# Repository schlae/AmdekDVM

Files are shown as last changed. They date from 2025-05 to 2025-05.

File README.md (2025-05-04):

# Amdek DVM Clone

The Amdek DVM allowed RGB digital monitors to be connected to Apple II
computers (which normally output composite video).

This project is a reverse-engineered version of this card.

It uses readily-available TTL logic chips, with no programmable devices at
all.

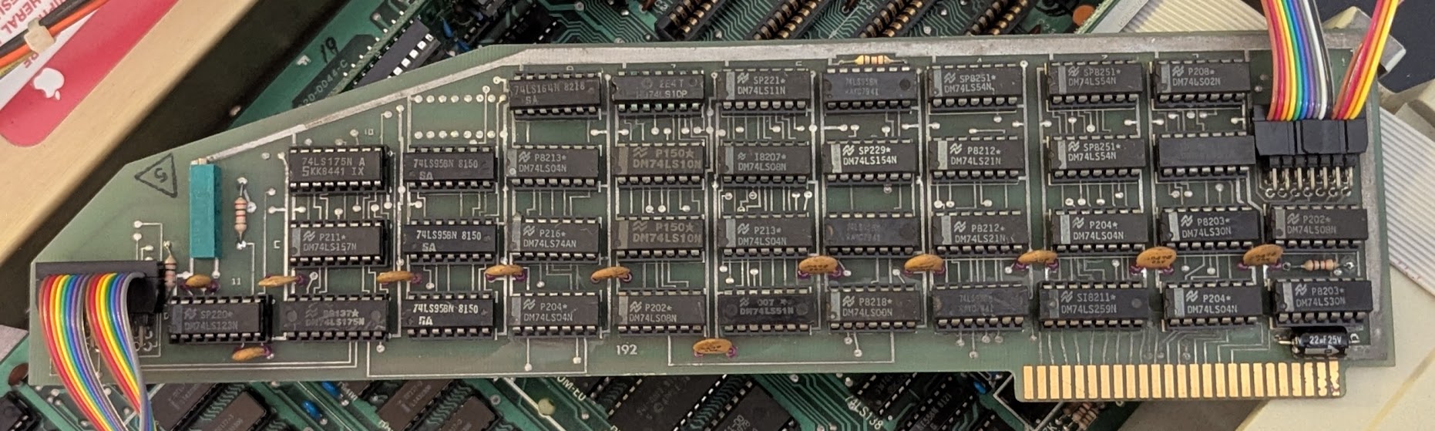
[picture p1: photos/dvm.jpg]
An original Amdek DVM card


*Note: The photo shows an original DVM card since I have not fabricated my design*

[Schematic](AmdekDVM.pdf)

[Bill of Materials](AmdekDVM.csv)

[Fab files](fab/AmdekDVM-Rev1.zip)

[Fab files for daughterboard](AmdekDaughterBoard/fab/AmdekDaughterBoard-Rev1.zip)

## Fabrication Notes

The main board is 280mm x 76mm (11" x 3"). It is a simple 2-layer board. It
has an edge connector on the bottom, and you may want to have it gold plated,
but this isn't strictly necessary. No edge bevel is required but it may make
it easier to insert into the connectors on the Apple II (or you could add
one with a file).

The daughterboard is 38mm x 87mm (1.5" x 3.435"). It is a simple 2-layer board
and could even be reduced down to a 1-layer design if you have access to such
a fab process.

## Assembly Notes

RV2 is actually a fixed resistor, 2K. Solder it from pin 1 to pin 3.

C3-C13 are just bypass capacitors and could easily be subbed out with 0.1uF.

C14-C23 are not stuffed on the original board, but it would be harmless
to place 0.1uF capacitors here.

The daughterboard (actually two separate boards, see the photos below) should
have machine-pin sockets installed. To allow them to be plugged into the Apple
II motherboard, solder additional socket pins (harvested from spare sockets)
to the ends of the pins protruding from the other side of the board. Alignment
is critical so that the pins will plug into the sockets on the Apple II.

The daughterboard can be assembled with regular 0.1" headers and 8-pin IDC
plugs, or you can use a combined part like the CA2308PA10Z. The cable is
split exactly in half, with the first 8 pins going to the 4-chip daughterboard
and the second 8 pins going to the 2-chip daughterboard (with wire 9 tied
to pin 1 of this daughterboard).

## Cables

To build this card, you will need a video output cable wired as follows. Plug
it into J2 (nearest the edge connector).

| Pin | Description |
|-----|---|
| 1 | Red output |
| 2 | Green output |
| 3 | Blue output |
| 4 | Horizontal sync (positive) |
| 5 | Horizontal sync (negative) |
| 6 | Vertical sync (positive) |
| 7 | Vertical sync (negative) |
| 8 | No connect |
| 9 | Ground |
| 10  | No connect |
| 11  | Apple II text - connect to Apple II header K14 pin 2 |
| 12  | Horizontal sync from 80-column card |
| 13  | Video signal from 80-column card |
| 14  | Vertical sync from 80-column card |

Pin 11 of this cable should be wired to the Apple II video header. On my
Apple II+, it looks like this.

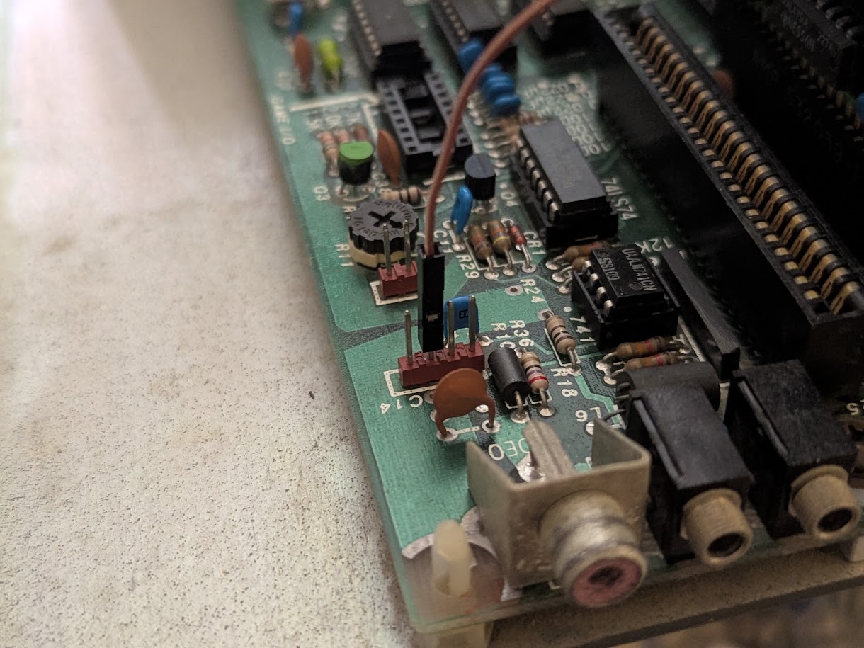
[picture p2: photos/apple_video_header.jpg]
Placement of the Apple II text connection


If you want to connect the DVM to a CGA-compatible monitor, wire it up as
follows:

| Amdek Pin | CGA Pin | Description |
|---|---|---|
| 1 |  3 | Red output  |
| 2 |  4 | Green output |
| 3 |  5 | Blue output |
| 4 |  8 | Horizontal sync (positive) |
| 6 |  9 | Vertical sync (positive) |
| 9 |  1 | Ground |

If you have an 80-column card, you can wire pins 12-14 to that card as
appropriate.

You will also need a cable connected to J1 (furthest from the edge connector)
wired to two daughterboards. The daughterboards act as interposers, tapping
various signals on the Apple II motherboard.

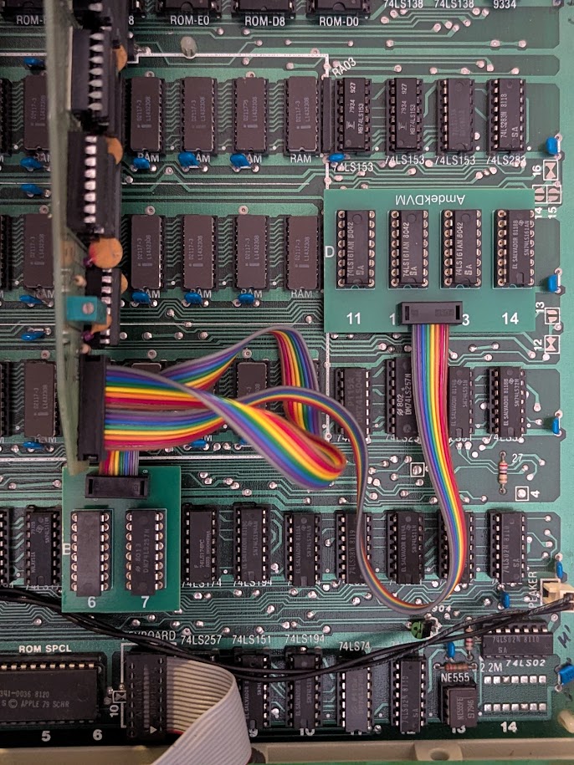
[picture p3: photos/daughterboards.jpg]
Placement of the daughterboards


* One daughterboard sits on motherboard positions D11, D12, D13, and D14,
hosting the four 74LS161 chips that the Apple II uses to generate the video
timing signals. It intercepts three horizontal counter bits and five vertical
counter bits.

* The other daughterboard sits on motherboard positions B6 and B7, hosting
two 74LS257 chips. This intercepts the eight digital video bits before
they go through encoding to composite video.

## Adjustments

When you install the card, ensure you get video out of your Apple II, then
adjust RV1 until you get stable pixels.

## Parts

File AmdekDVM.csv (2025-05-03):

Qty | Reference | Value | DNP | Exclude from BOM | Exclude from Board
1 | C1 | 100
1 | C2 | 33
10 | C3,C4,C5,C6,C7,C8,C9,C10,C11,C12 | 0.047
1 | C13 | 22uF 25V
10 | C14,C15,C16,C17,C18,C19,C20,C21,C22,C23 | DNI
1 | J1 | TO_DAUGHTERBOARD
1 | J2 | VIDEO
1 | J3 | APPLE II
1 | R1 | 10K
2 | R2,R3 | 1K
1 | RV1 | 5K
1 | RV2 | 2K
1 | U1 | 74LS123
2 | U2,U4 | 74LS175
1 | U3 | 74LS157
1 | U5 | SPARE
6 | U6,U7,U8,U21,U23,U28 | 74LS95
2 | U9,U22 | 74LS164
5 | U10,U12,U19,U31,U36 | 74LS04
1 | U11 | 74LS74
3 | U13,U14,U15 | 74LS10
3 | U16,U18,U37 | 74LS08
1 | U17 | 74LS11
2 | U20,U34 | 74LS51
1 | U24 | 74LS00
3 | U25,U29,U30 | 74LS54N
2 | U26,U27 | 74LS21
1 | U32 | 74LS259
1 | U33 | 74LS02
2 | U35,U38 | 74LS30

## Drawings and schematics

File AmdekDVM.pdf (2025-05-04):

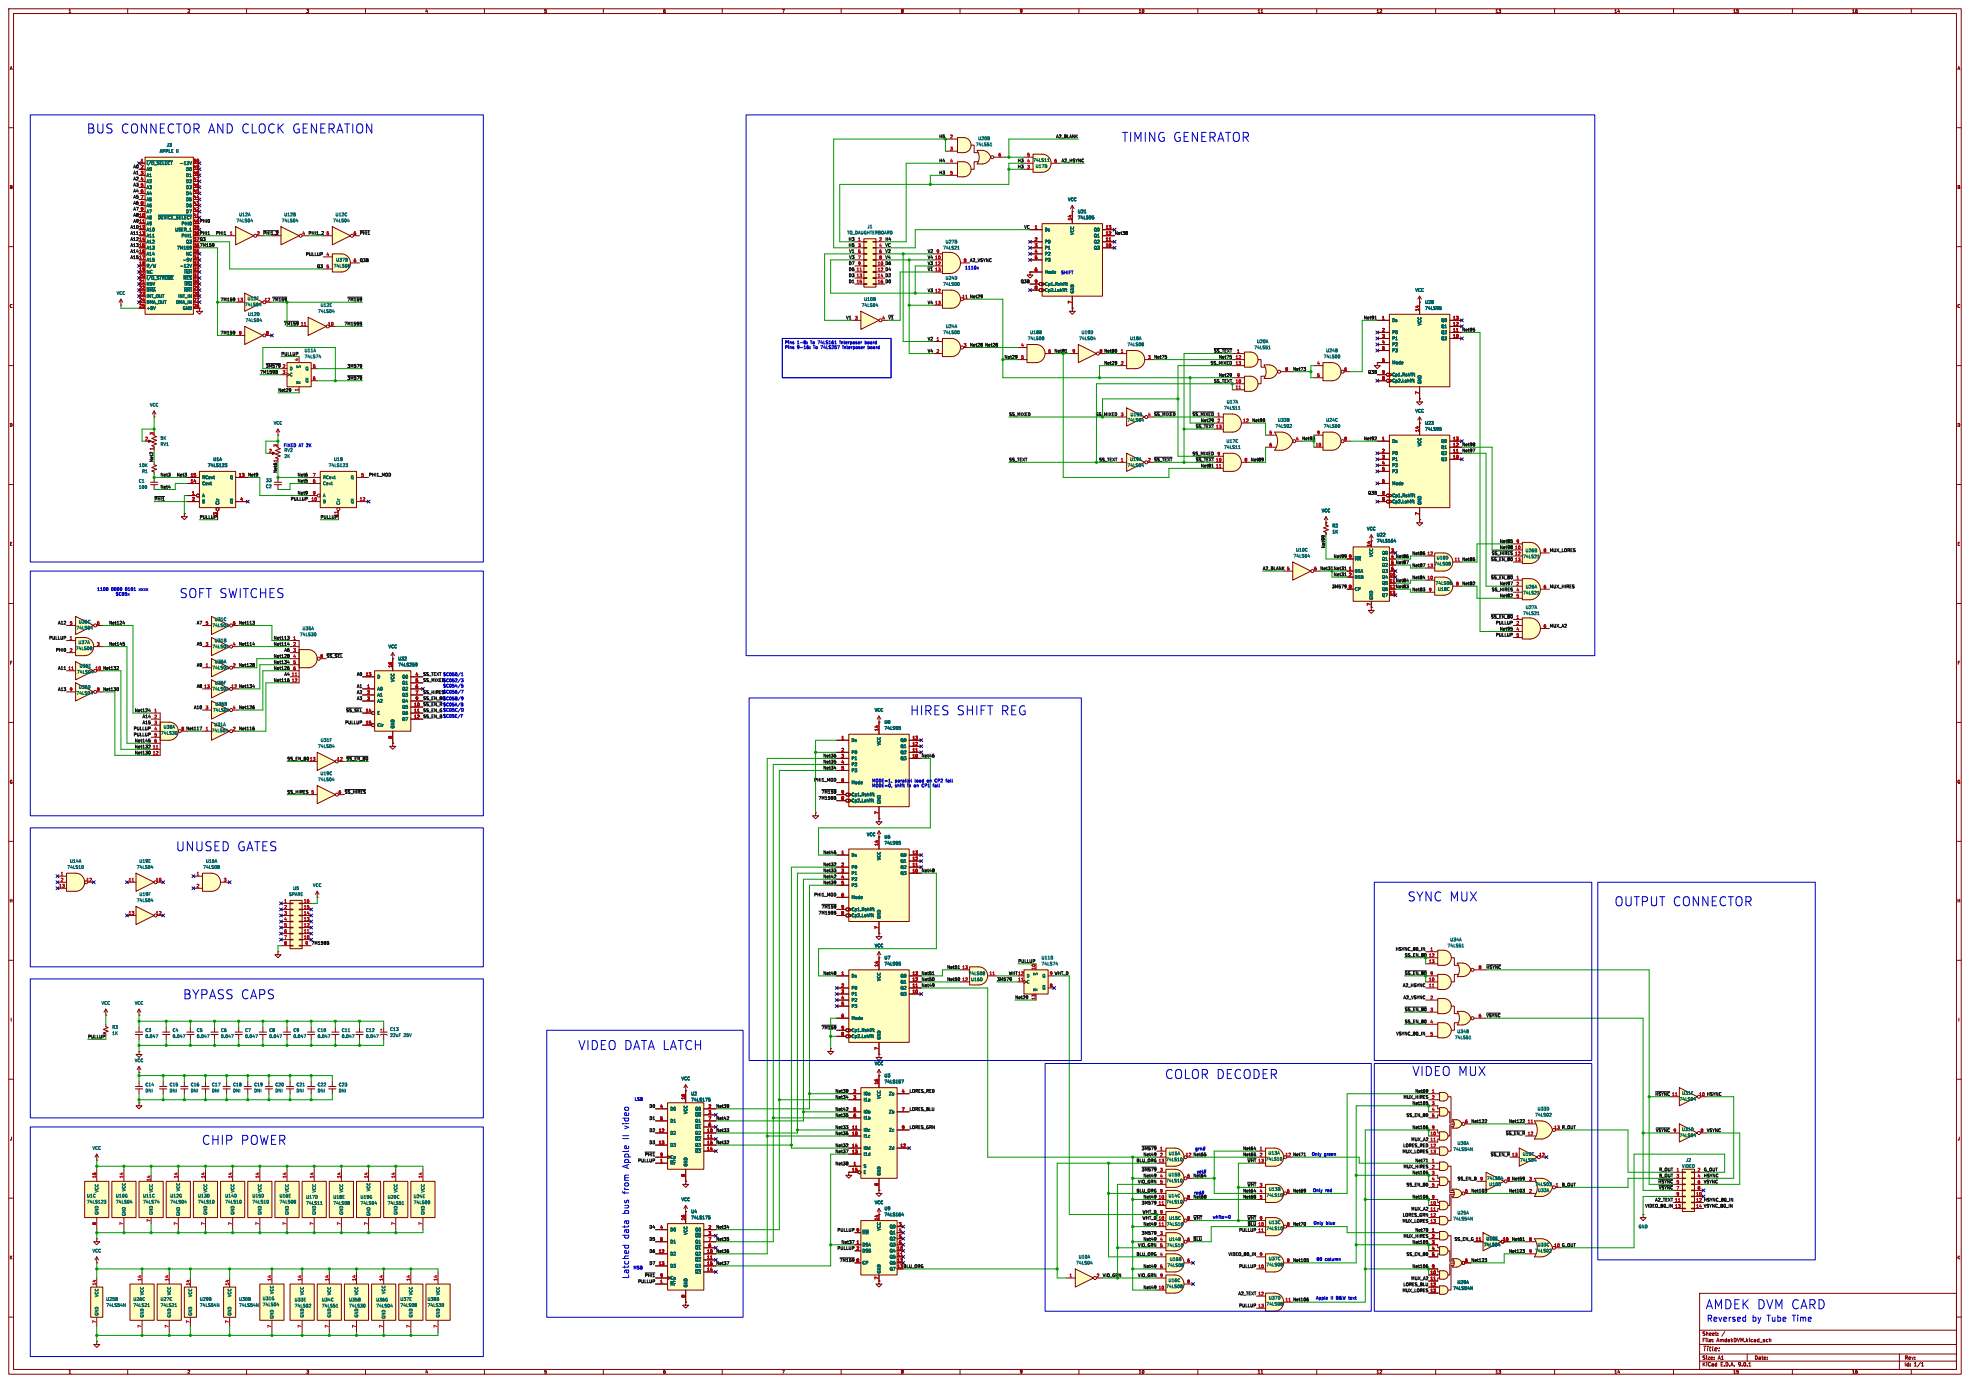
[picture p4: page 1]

BUS CONNECTOR AND CLOCK GENERATION
J3 APPLE II ~{I/O_SELECT} 1 A0 2 A1 3 A2 4 A3 5 A4 6 A5 7 A6 8 A7 9 A8 10 A9 11 A10 12 A11 13 A12 14 A13 15 A14 16 A15 17 R/W 18 NC 19 ~{I/O_STROBE} 20 RDY 21 ~{DMA} 22
-12V 50 D0 49 D1 48 D2 47 D3 46 D4 45 D5 44 D6 43 D7 42 ~{DEVICE_SELECT} 41 PHI0 40 USER_1 39 PHI1 38 Q3 37

-12V 33 ~{INH}32 ~{RES} 31 ~{IRQ} 30 ~{NMI}29

Only blue CHIP POWER

AMDEK DVM CARD
Reversed by Tube Time

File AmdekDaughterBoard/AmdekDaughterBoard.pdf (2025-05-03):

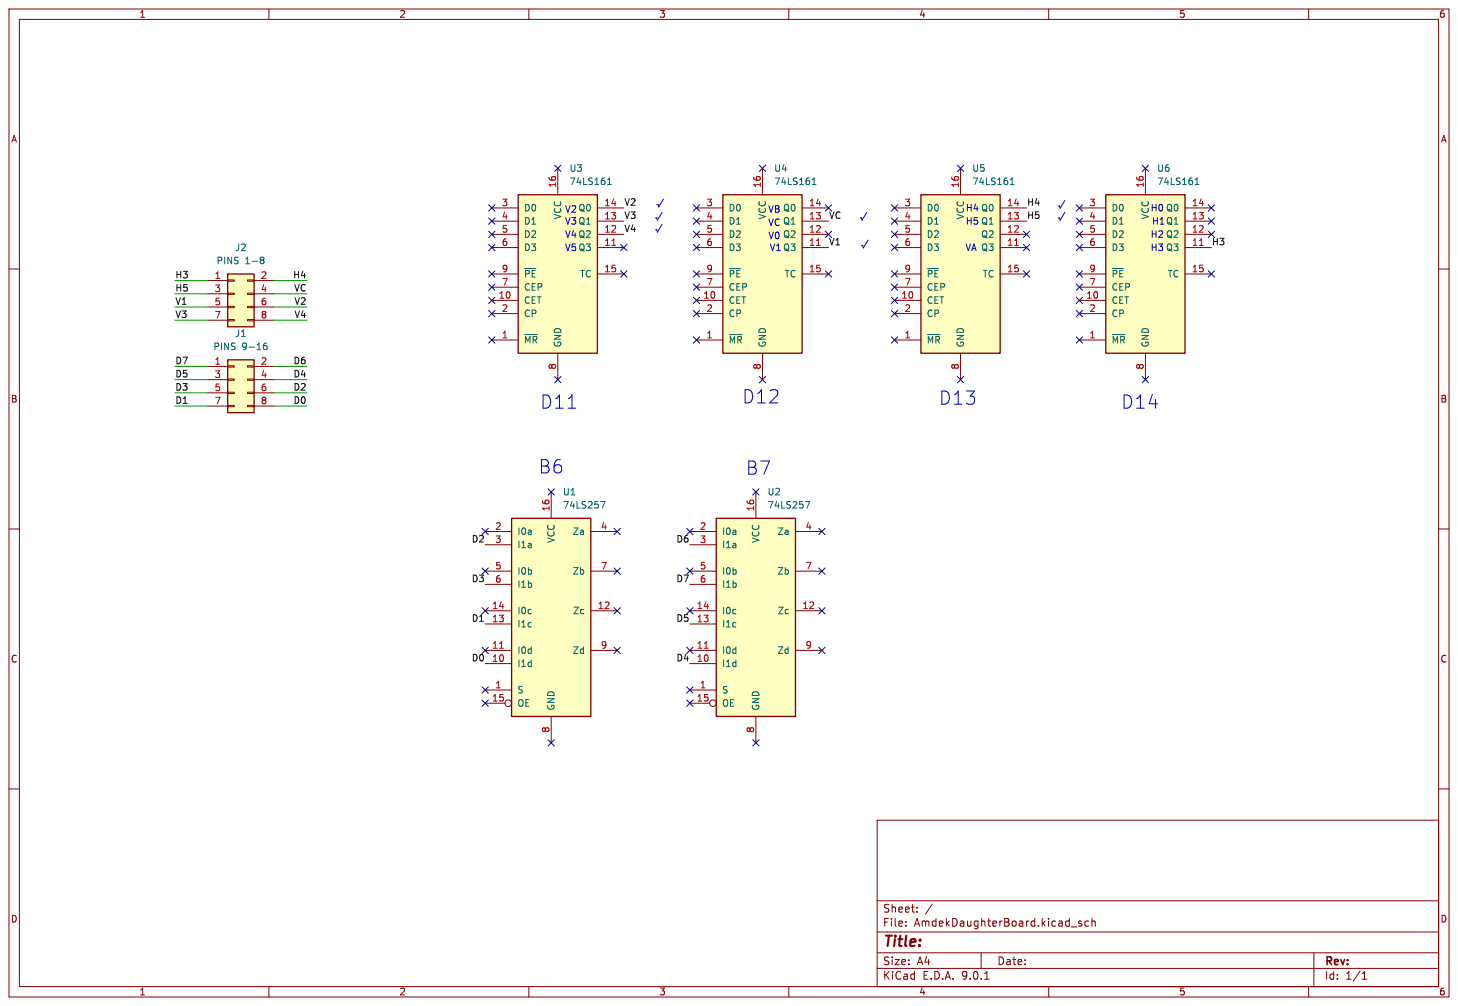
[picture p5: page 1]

Id: 1/1 Title: File: AmdekDaughterBoard.kicad_sch Sheet: /

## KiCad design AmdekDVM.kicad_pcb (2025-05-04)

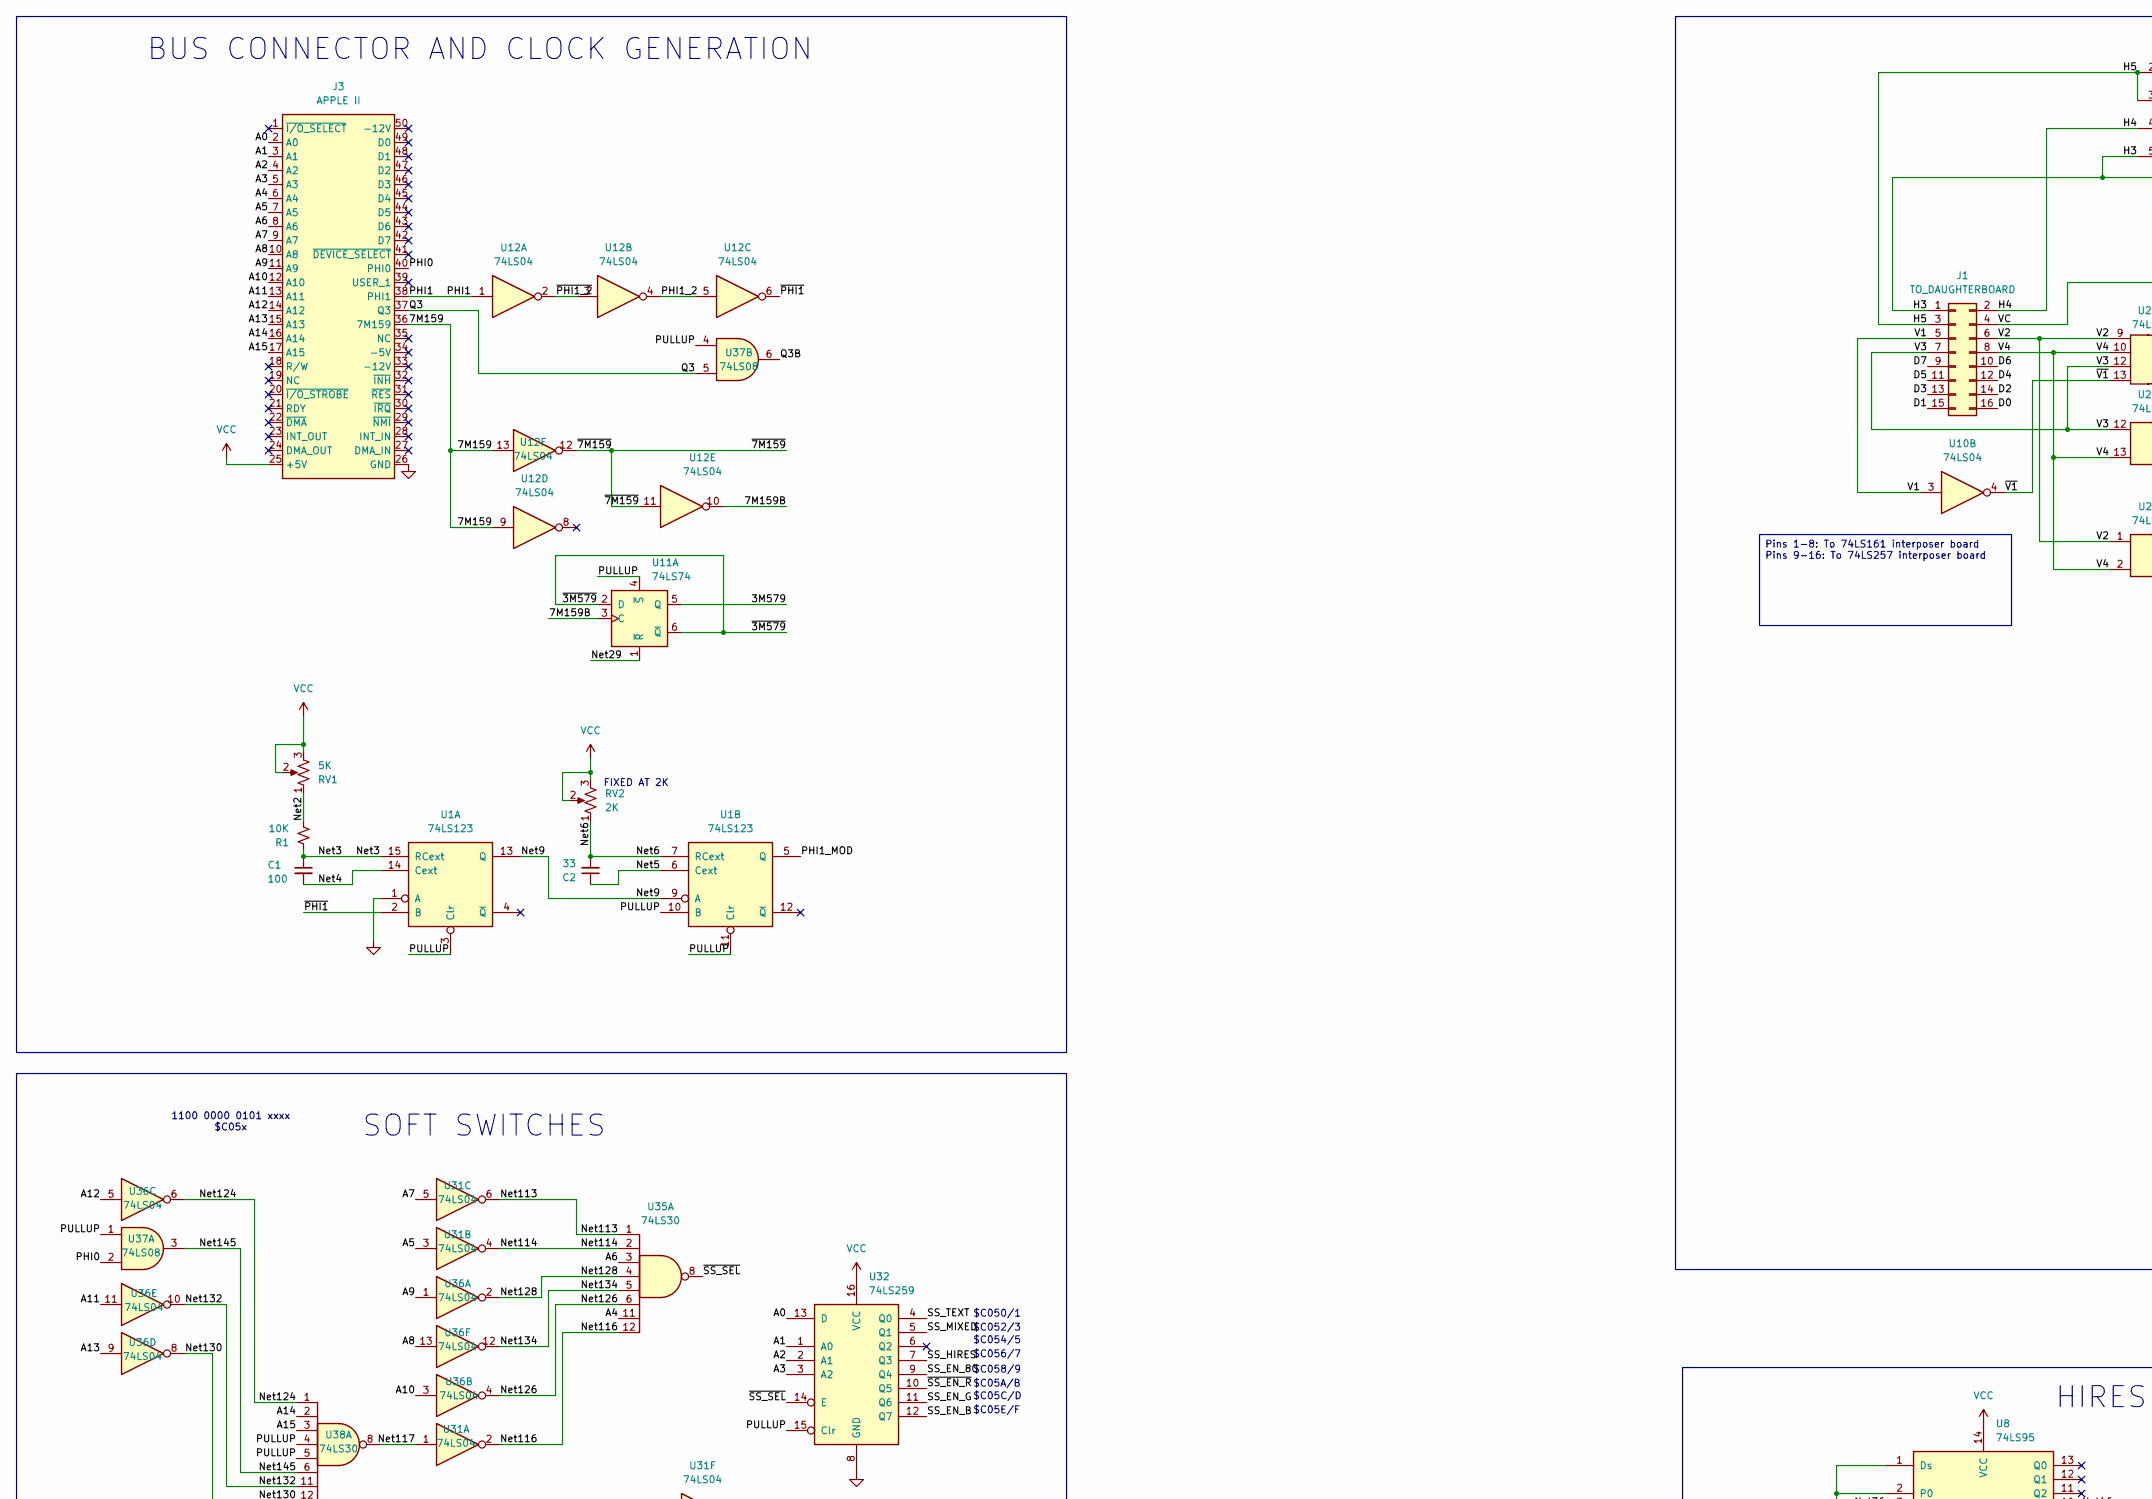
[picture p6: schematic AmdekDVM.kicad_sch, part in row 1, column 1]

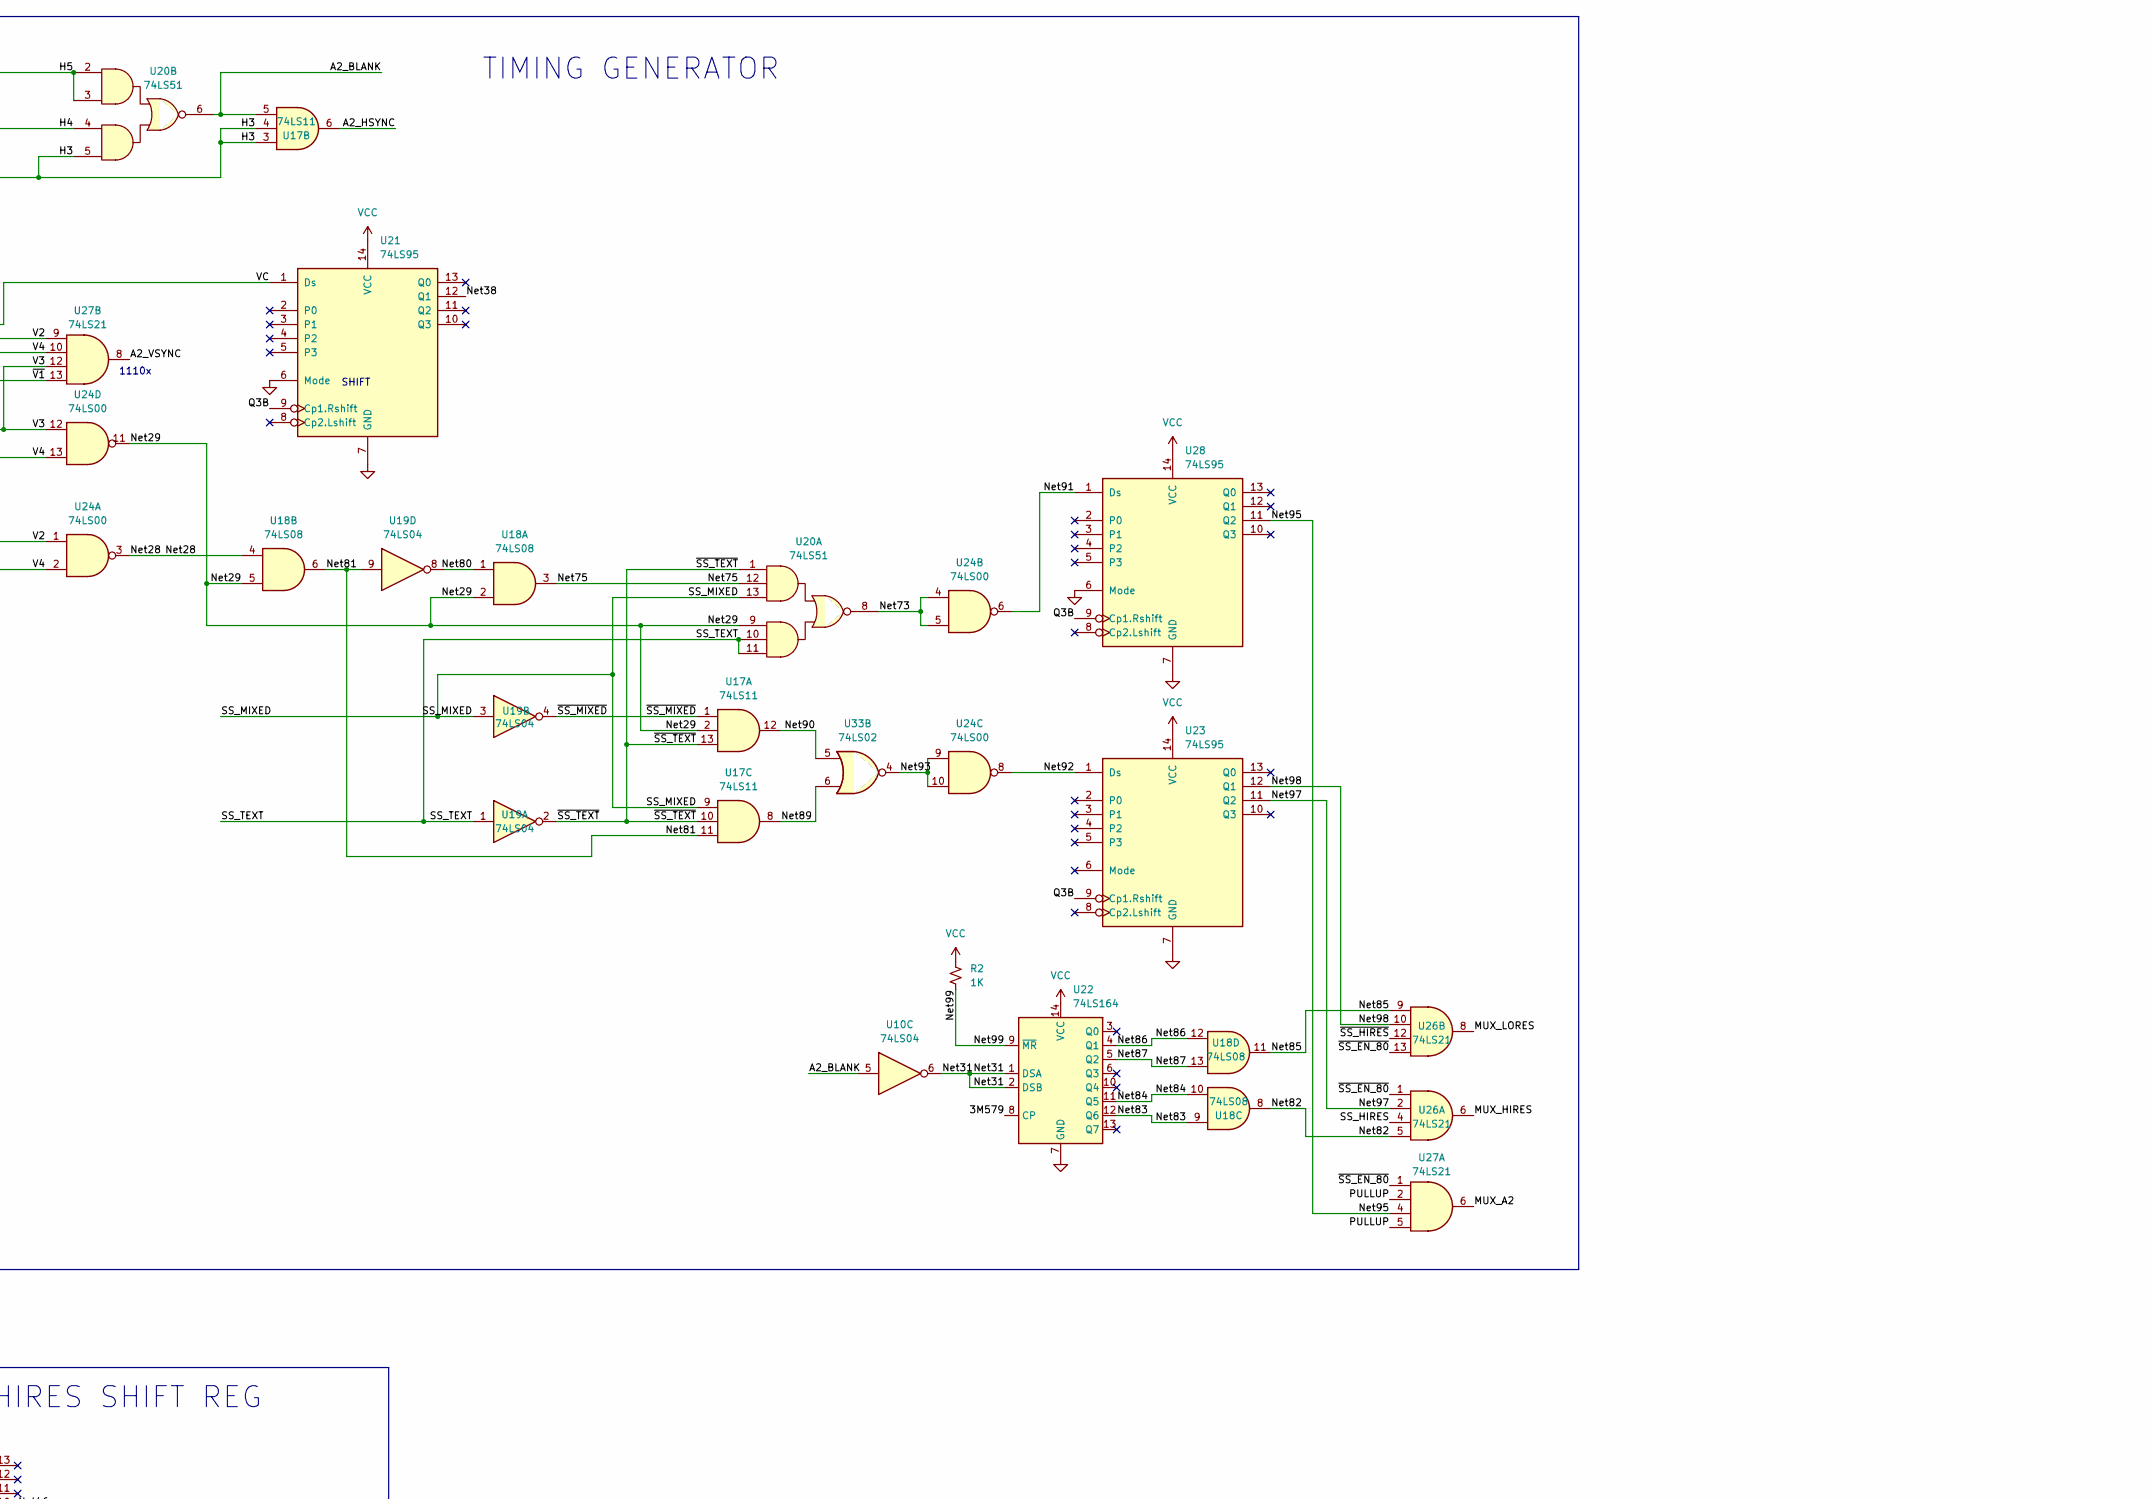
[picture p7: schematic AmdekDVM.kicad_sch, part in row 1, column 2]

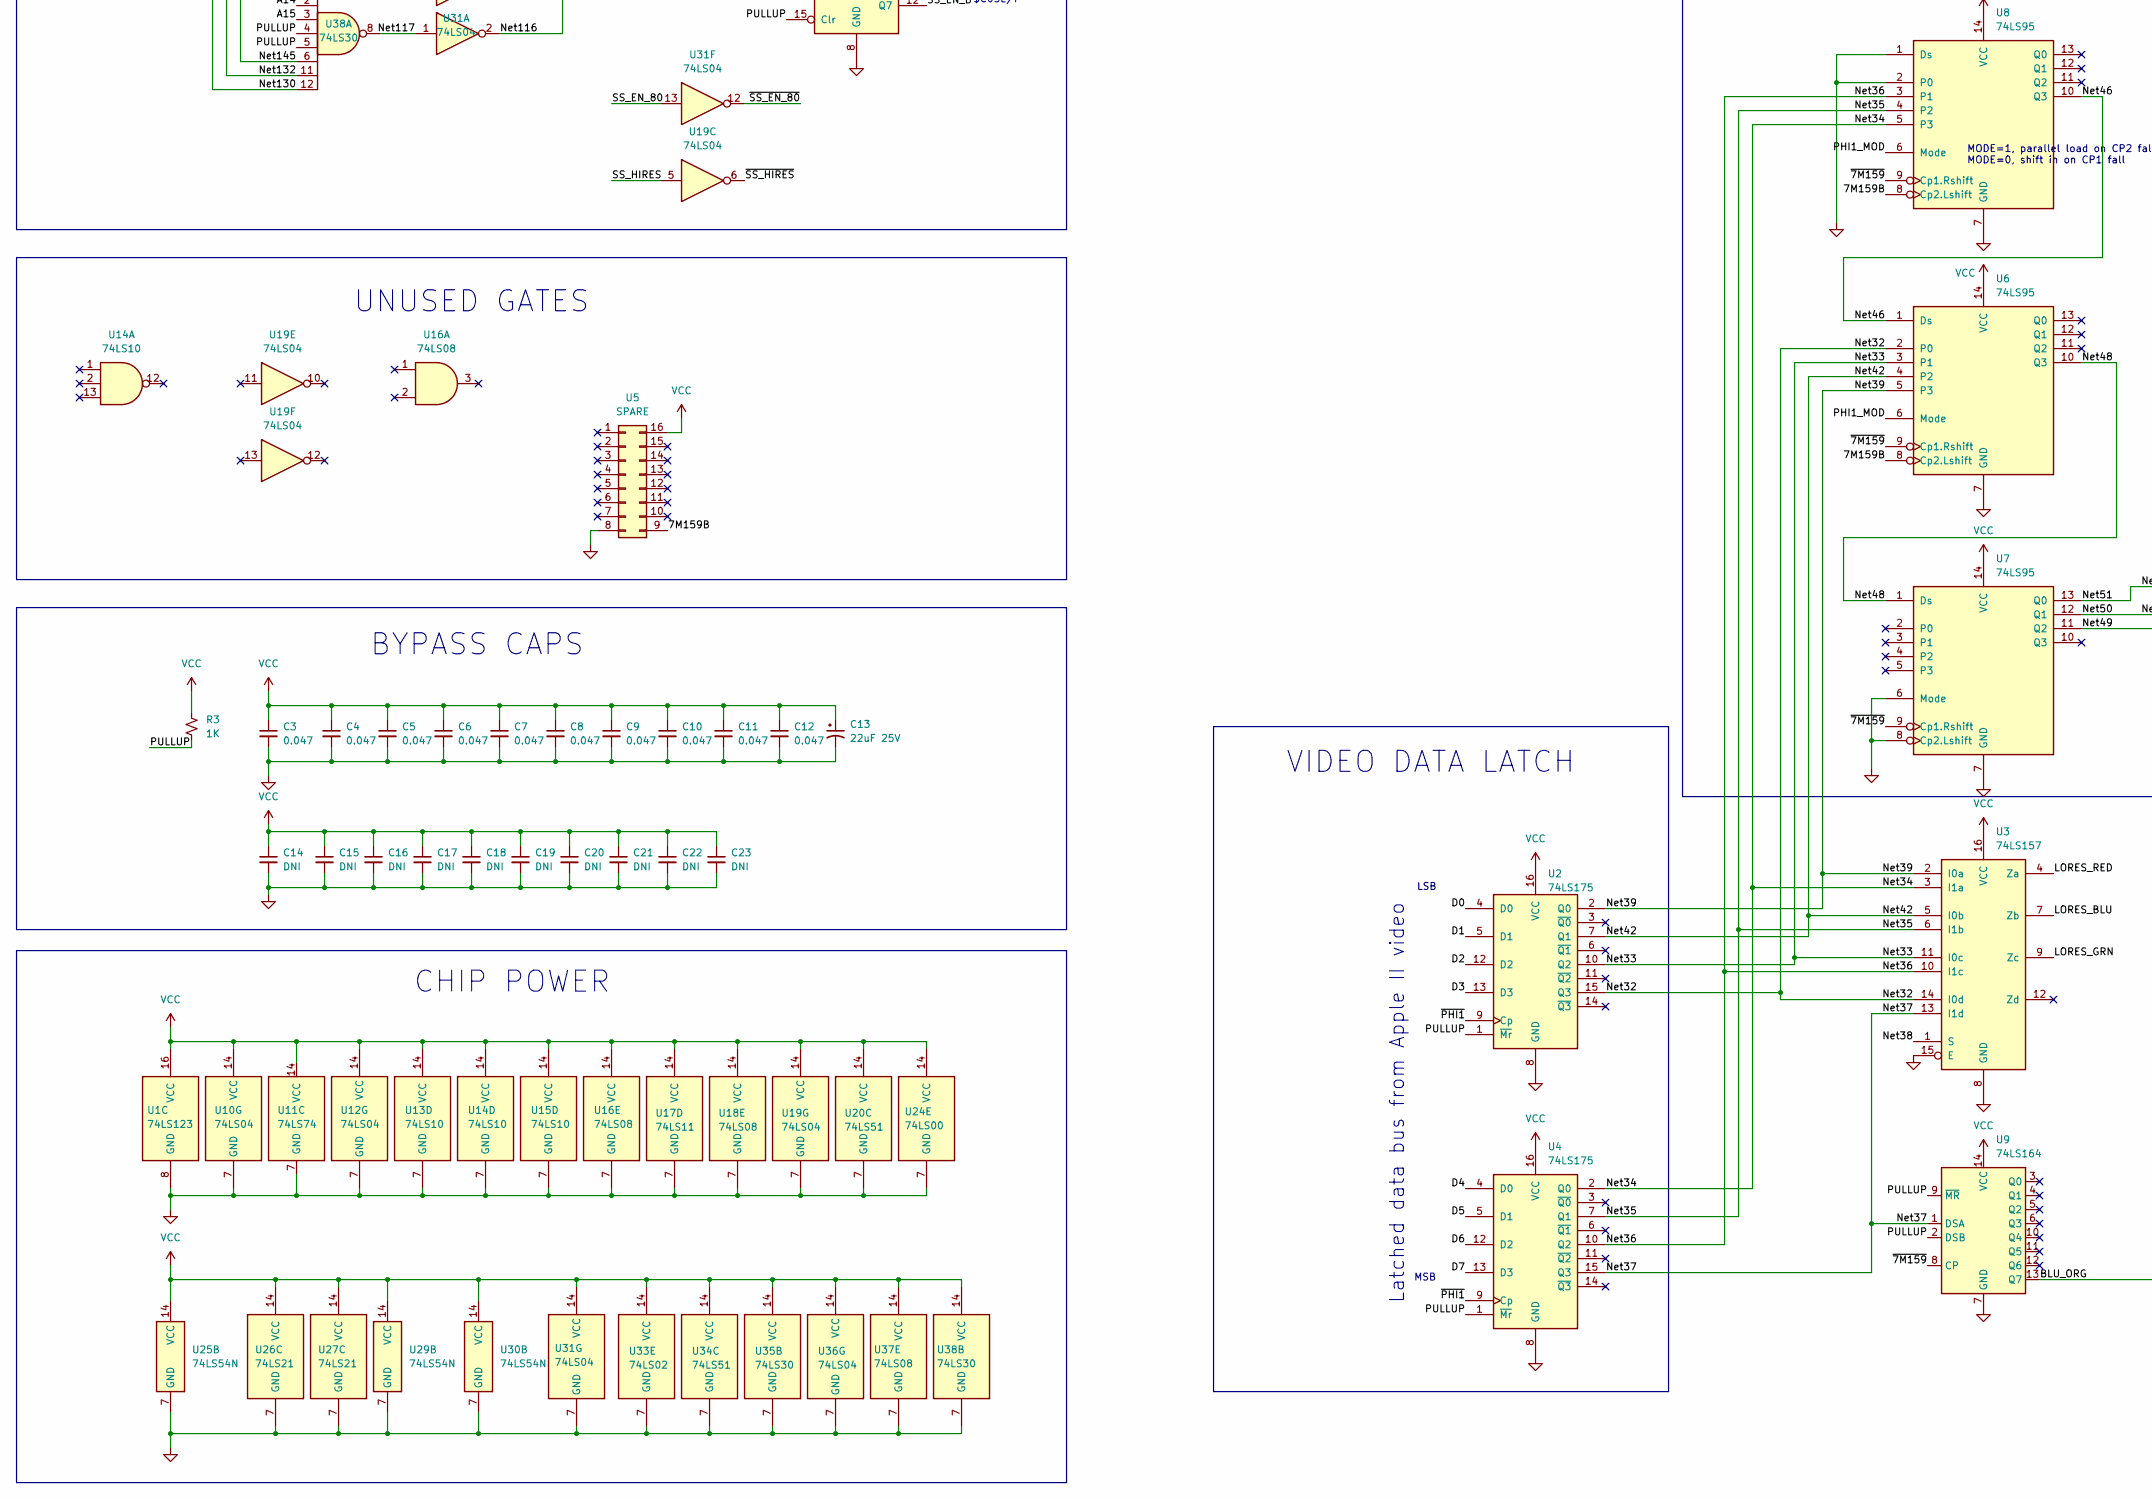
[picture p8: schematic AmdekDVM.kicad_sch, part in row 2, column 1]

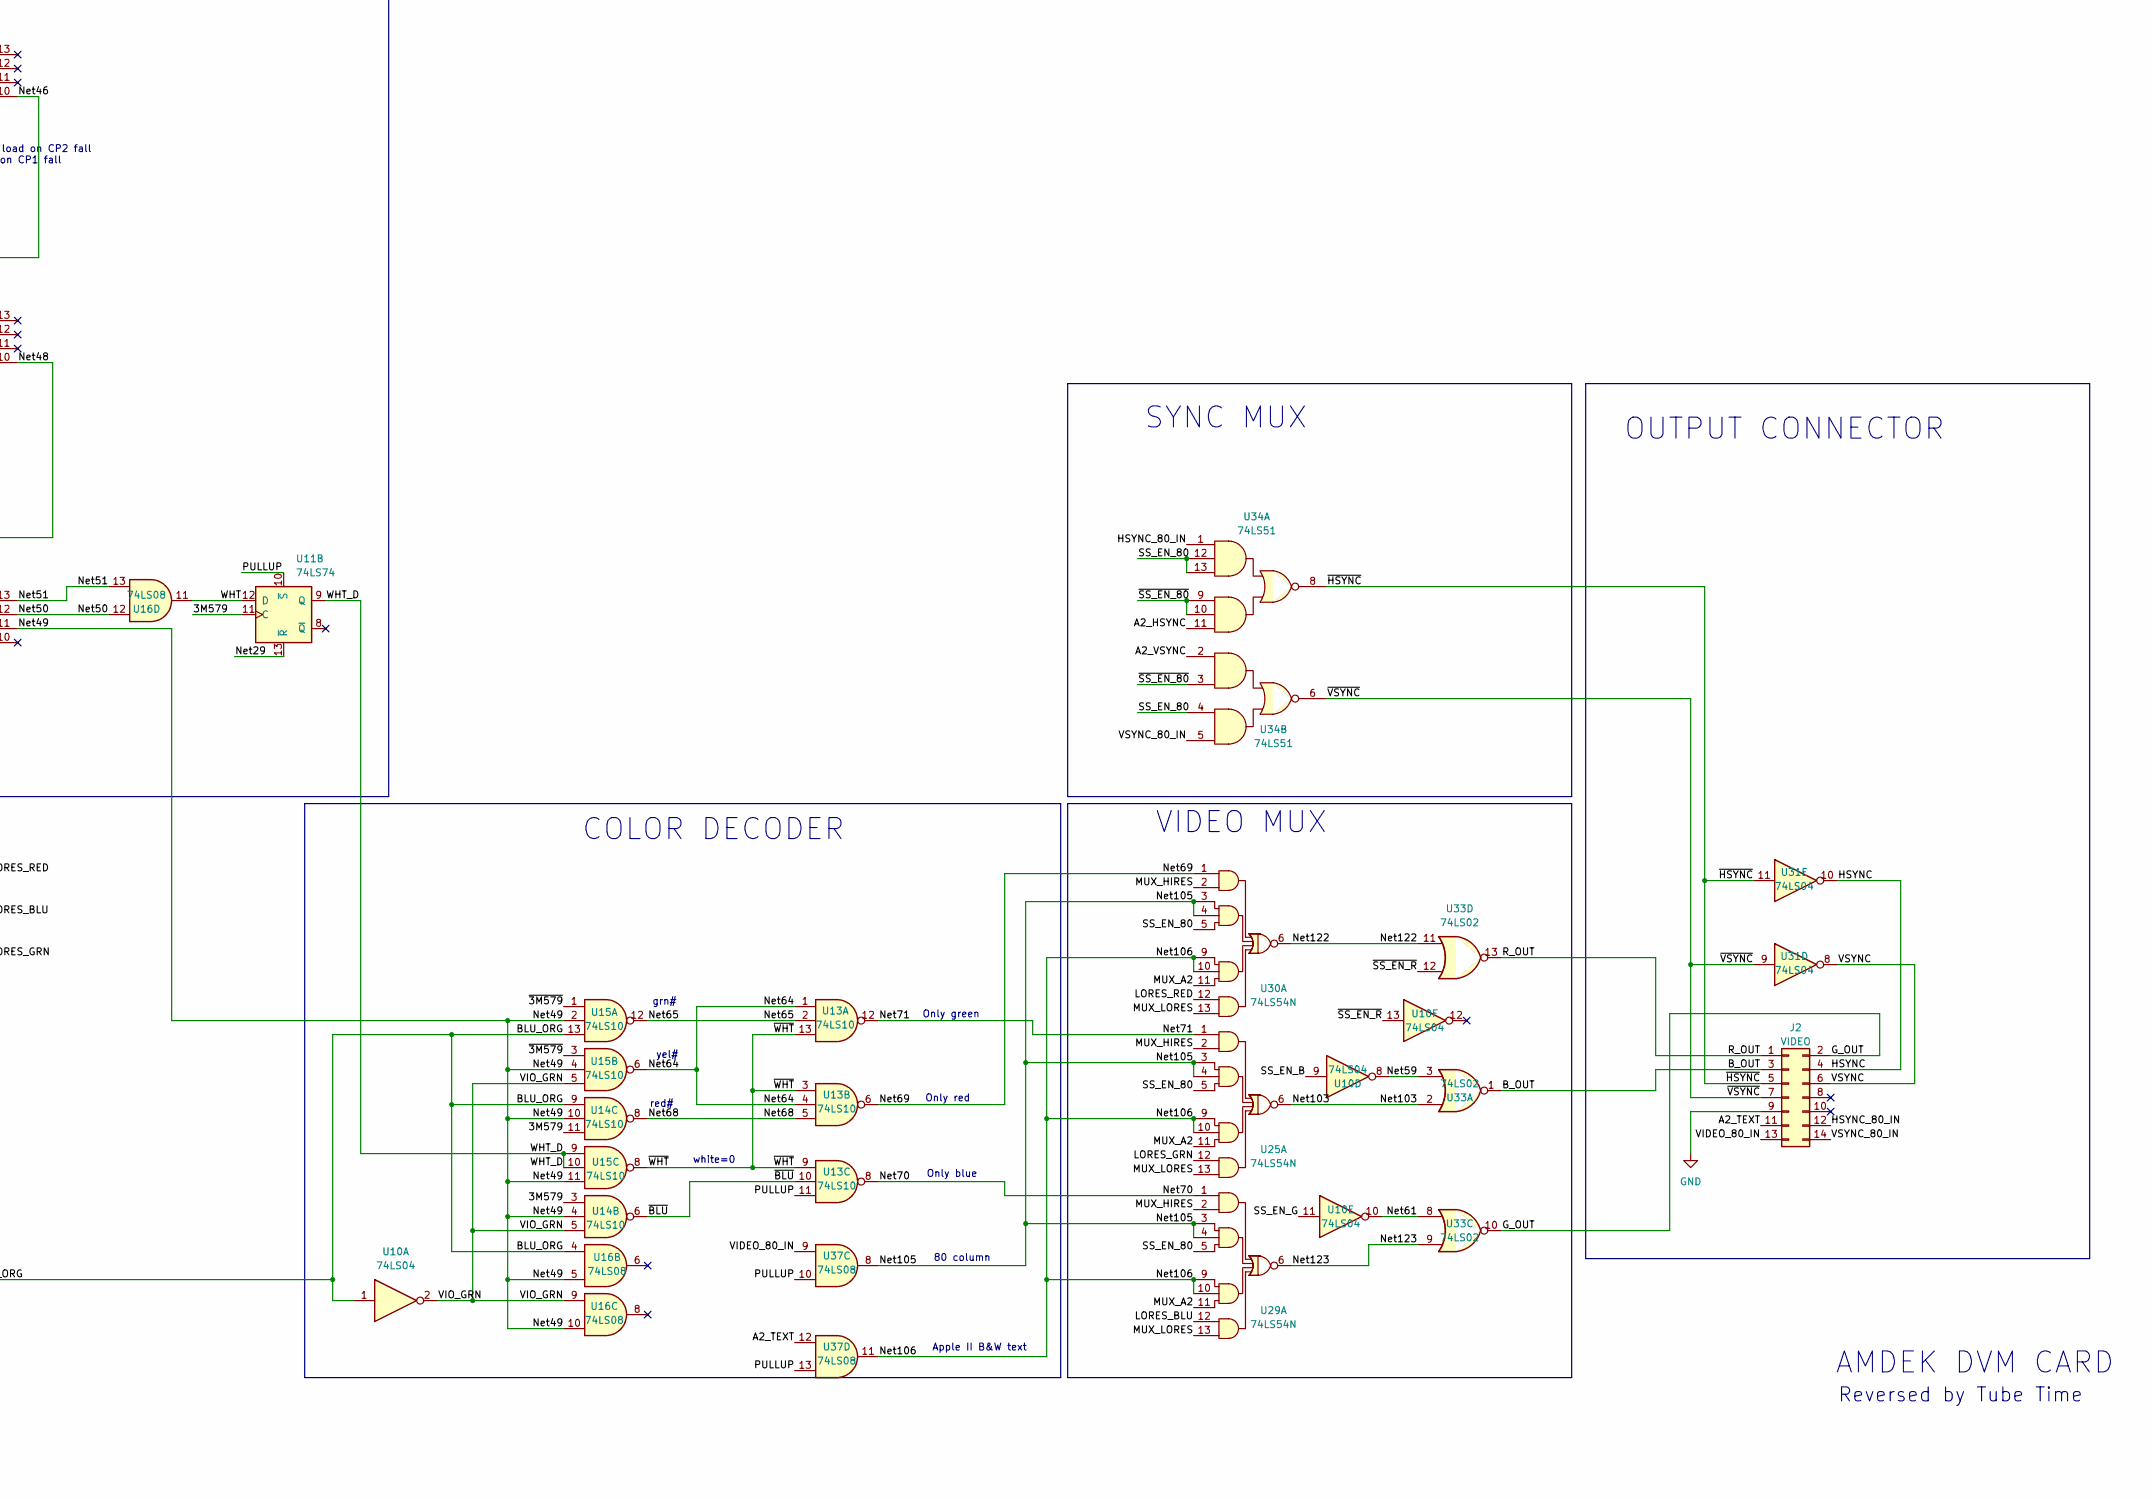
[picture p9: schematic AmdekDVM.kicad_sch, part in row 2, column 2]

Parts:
C1: 100; C_Disc_D4.3mm_W1.9mm_P5.00mm
C2: 33; C_Disc_D4.3mm_W1.9mm_P5.00mm
C3, C4, C5, C6, C7, C8, C9, C10, C11, C12: 0.047; C_Disc_D4.3mm_W1.9mm_P5.00mm
C13: 22uF 25V; CP_Axial_L10.0mm_D4.5mm_P15.00mm_Horizontal
C14, C15, C16, C17, C18, C19, C20, C21, C22, C23: DNI; C_Disc_D4.3mm_W1.9mm_P5.00mm
J1: TO_DAUGHTERBOARD; PinHeader_2x08_P2.54mm_Horizontal
J2: VIDEO; PinHeader_2x07_P2.54mm_Horizontal
J3: APPLE II; APPLE_II
R1: 10K; R_Axial_DIN0309_L9.0mm_D3.2mm_P12.70mm_Horizontal
R2, R3: 1K; R_Axial_DIN0309_L9.0mm_D3.2mm_P12.70mm_Horizontal
RV1: 5K; Potentiometer_Bourns_3006P_Horizontal
RV2: 2K; Potentiometer_Bourns_3006P_Horizontal
U1: 74LS123; DIP-16_W7.62mm
U2, U4: 74LS175; DIP-16_W7.62mm
U3: 74LS157; DIP-16_W7.62mm
U5: SPARE; DIP-16_W7.62mm
U6, U7, U8, U21, U23, U28: 74LS95; DIP-14_W7.62mm
U9, U22: 74LS164; DIP-14_W7.62mm
U10, U12, U19, U31, U36: 74LS04; DIP-14_W7.62mm
U11: 74LS74; DIP-14_W7.62mm
U13, U14, U15: 74LS10; DIP-14_W7.62mm
U16, U18, U37: 74LS08; DIP-14_W7.62mm
U17: 74LS11; DIP-14_W7.62mm
U20, U34: 74LS51; DIP-14_W7.62mm
U24: 74LS00; DIP-14_W7.62mm
U25, U29, U30: 74LS54N; DIP-14_W7.62mm
U26, U27: 74LS21; DIP-14_W7.62mm
U32: 74LS259; DIP-16_W7.62mm
U33: 74LS02; DIP-14_W7.62mm
U35, U38: 74LS30; DIP-14_W7.62mm

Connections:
/3M579: U11.5 (Q), U11.11 (C), U14.3, U14.11, U22.8 (CP)
/7M159: J3.36 (7M159), U12.9, U12.13
/7M159B: U5.9, U6.8 (Cp2.Lshift), U8.8 (Cp2.Lshift), U11.3 (C), U12.10
/A0: J3.2 (A0), U32.13 (D)
/A1: J3.3 (A1), U32.1 (A0)
/A2: J3.4 (A2), U32.2 (A1)
/A2_BLANK: U10.5, U17.5, U20.6
/A2_HSYNC: U17.6, U34.11
/A2_TEXT: J2.11, U37.12
/A2_VSYNC: U27.8, U34.2
/A3: J3.5 (A3), U32.3 (A2)
/A4: J3.6 (A4), U35.11
/A5: J3.7 (A5), U31.3
/A6: J3.8 (A6), U35.3
/A7: J3.9 (A7), U31.5
/A8: J3.10 (A8), U36.13
/A9: J3.11 (A9), U36.1
/A10: J3.12 (A10), U36.3
/A11: J3.13 (A11), U36.11
/A12: J3.14 (A12), U36.5
/A13: J3.15 (A13), U36.9
/A14: J3.16 (A14), U38.2
/A15: J3.17 (A15), U38.3
/BLU_ORG: U9.13 (Q7), U10.1, U14.9, U15.13, U16.4
/B_OUT: J2.3, U33.1
/D0: J1.16, U2.4 (D0)
/D1: J1.15, U2.5 (D1)
/D2: J1.14, U2.12 (D2)
/D3: J1.13, U2.13 (D3)
/D4: J1.12, U4.4 (D0)
/D5: J1.11, U4.5 (D1)
/D6: J1.10, U4.12 (D2)
/D7: J1.9, U4.13 (D3)
/G_OUT: J2.2, U33.10
/H3: J1.1, U17.3, U17.4, U20.5
/H4: J1.2, U20.4
/H5: J1.3, U20.2, U20.3
/HSYNC: J2.4, U31.10
/HSYNC_80_IN: J2.12, U34.1
/LORES_BLU: U3.7 (Zb), U29.12
/LORES_GRN: U3.9 (Zc), U25.12
/LORES_RED: U3.4 (Za), U30.12
/MUX_A2: U25.11, U27.6, U29.11, U30.11
/MUX_HIRES: U25.2, U26.6, U29.2, U30.2
/MUX_LORES: U25.13, U26.8, U29.13, U30.13
/Net2: R1.2, RV1.1
/Net3: C1.1, R1.1, U1.15 (RCext)
/Net4: C1.2, U1.14 (Cext)
/Net5: C2.1, U1.6 (Cext)
/Net6: C2.2, RV2.1, U1.7 (RCext)
/Net9: U1.9 (A), U1.13 (Q)
/Net28: U18.4, U24.3
/Net29: U11.1 (~R), U11.13 (~R), U17.2, U18.2, U18.5, U20.9, U24.11
/Net31: U10.6, U22.1 (DSA), U22.2 (DSB)
/Net32: U2.15 (Q3), U3.14 (I0d), U6.2 (P0)
/Net33: U2.10 (Q2), U3.11 (I0c), U6.3 (P1)
/Net34: U3.3 (I1a), U4.2 (Q0), U8.5 (P3)
/Net35: U3.6 (I1b), U4.7 (Q1), U8.4 (P2)
/Net36: U3.10 (I1c), U4.10 (Q2), U8.3 (P1)
/Net37: U3.13 (I1d), U4.15 (Q3), U9.1 (DSA)
/Net38: U3.1 (S), U21.12 (Q1)
/Net39: U2.2 (Q0), U3.2 (I0a), U6.5 (P3)
/Net42: U2.7 (Q1), U3.5 (I0b), U6.4 (P2)
/Net46: U6.1 (Ds), U8.10 (Q3)
/Net48: U6.10 (Q3), U7.1 (Ds)
/Net49: U7.11 (Q2), U14.4, U14.10, U15.2, U15.4, U15.11, U16.5, U16.10
/Net50: U7.12 (Q1), U16.12
/Net51: U7.13 (Q0), U16.13
/Net59: U10.8, U33.3
/Net61: U10.10, U33.8
/Net64: U13.1, U13.4, U15.6
/Net65: U13.2, U15.12
/Net68: U13.5, U14.8
/Net69: U13.6, U30.1
/Net70: U13.8, U29.1
/Net71: U13.12, U25.1
/Net73: U20.8, U24.4, U24.5
/Net75: U18.3, U20.12
/Net80: U18.1, U19.8
/Net81: U17.11, U18.6, U19.9
/Net82: U18.8, U26.5
/Net83: U18.9, U22.12 (Q6)
/Net84: U18.10, U22.11 (Q5)
/Net85: U18.11, U26.9
/Net86: U18.12, U22.4 (Q1)
/Net87: U18.13, U22.5 (Q2)
/Net89: U17.8, U33.6
/Net90: U17.12, U33.5
/Net91: U24.6, U28.1 (Ds)
/Net92: U23.1 (Ds), U24.8
/Net93: U24.9, U24.10, U33.4
/Net95: U27.4, U28.11 (Q2)
/Net97: U23.11 (Q2), U26.2
/Net98: U23.12 (Q1), U26.10
/Net99: R2.2, U22.9 (~MR)
/Net103: U25.6, U33.2
/Net105: U25.3, U25.4, U29.3, U29.4, U30.3, U30.4, U37.8
/Net106: U25.9, U25.10, U29.9, U29.10, U30.9, U30.10, U37.11
/Net113: U31.6, U35.1
/Net114: U31.4, U35.2
/Net116: U31.2, U35.12
/Net117: U31.1, U38.8
/Net122: U30.6, U33.11
/Net123: U29.6, U33.9
/Net124: U36.6, U38.1
/Net126: U35.6, U36.4
/Net128: U35.4, U36.2
/Net130: U36.8, U38.12
/Net132: U36.10, U38.11
/Net134: U35.5, U36.12
/Net145: U37.3, U38.6
/PHI0: J3.40 (PHI0), U37.2
/PHI1: J3.38 (PHI1), U12.1
/PHI1_2: U12.4, U12.5
/PHI1_MOD: U1.5 (Q), U6.6 (Mode), U8.6 (Mode)
/PULLUP: R3.2, U1.3 (Clr), U1.10 (B), U1.11 (Clr), U2.1 (~Mr), U4.1 (~Mr), U9.2 (DSB), U9.9 (~MR), U11.4 (~S), U11.10 (~S), U13.11, U27.2, U27.5, U32.15 (Clr), U37.1, U37.4, U37.10, U37.13, U38.4, U38.5
/Q3: J3.37 (Q3), U37.5
/Q3B: U21.9 (Cp1.Rshift), U23.9 (Cp1.Rshift), U28.9 (Cp1.Rshift), U37.6
/R_OUT: J2.1, U33.13
/SS_EN_80: U25.5, U29.5, U30.5, U31.13, U32.9 (Q4), U34.4, U34.12, U34.13
/SS_EN_B: U10.9, U32.12 (Q7)
/SS_EN_G: U10.11, U32.11 (Q6)
/SS_HIRES: U19.5, U26.4, U32.7 (Q3)
/SS_MIXED: U17.9, U19.3, U20.13, U32.5 (Q1)
/SS_TEXT: U19.1, U20.10, U20.11, U32.4 (Q0)
/V1: J1.5, U10.3
/V2: J1.6, U24.1, U27.9
/V3: J1.7, U24.12, U27.12
/V4: J1.8, U24.2, U24.13, U27.10
/VC: J1.4, U21.1 (Ds)
/VIDEO_80_IN: J2.13, U37.9
/VIO_GRN: U10.2, U14.5, U15.5, U16.9
/VSYNC: J2.6, U31.8
/VSYNC_80_IN: J2.14, U34.5
/WHT: U11.12 (D), U16.11
/WHT_D: U11.9 (Q), U15.9, U15.10
/~3M579: U11.2 (D), U11.6 (~Q), U15.1, U15.3
/~7M159: U6.9 (Cp1.Rshift), U7.9 (Cp1.Rshift), U8.9 (Cp1.Rshift), U9.8 (CP), U12.11, U12.12
/~BLU: U13.10, U14.6
/~HSYNC: J2.5, U31.11, U34.8
/~PHI1_2: U12.2, U12.3
/~PHI1: U1.2 (B), U2.9 (Cp), U4.9 (Cp), U12.6
/~SS_EN_80: U26.1, U26.13, U27.1, U31.12, U34.3, U34.9, U34.10
/~SS_EN_R: U10.13, U32.10 (Q5), U33.12
/~SS_HIRES: U19.6, U26.12
/~SS_MIXED: U17.1, U19.4
/~SS_SEL: U32.14 (E), U35.8
/~SS_TEXT: U17.10, U17.13, U19.2, U20.1
/~V1: U10.4, U27.13
/~VSYNC: J2.7, U31.9, U34.6
/~WHT: U13.3, U13.9, U13.13, U15.8
GND: C3.2, C4.2, C5.2, C6.2, C7.2, C8.2, C9.2, C10.2, C11.2, C12.2, C13.2, C14.2, C15.2, C16.2, C17.2, C18.2, C19.2, C20.2, C21.2, C22.2, C23.2, J2.9, J3.26 (GND), U1.1 (A), U1.8 (GND), U2.8 (GND), U3.8 (GND), U3.15 (E), U4.8 (GND), U5.8, U6.7 (GND), U7.6 (Mode), U7.7 (GND), U7.8 (Cp2.Lshift), U8.1 (Ds), U8.2 (P0), U8.7 (GND), U9.7 (GND), U10.7 (GND), U11.7 (GND), U12.7 (GND), U13.7 (GND), U14.7 (GND), U15.7 (GND), U16.7 (GND), U17.7 (GND), U18.7 (GND), U19.7 (GND), U20.7 (GND), U21.6 (Mode), U21.7 (GND), U22.7 (GND), U23.7 (GND), U24.7 (GND), U25.7 (GND), U26.7 (GND), U27.7 (GND), U28.6 (Mode), U28.7 (GND), U29.7 (GND), U30.7 (GND), U31.7 (GND), U32.8 (GND), U33.7 (GND), U34.7 (GND), U35.7 (GND), U36.7 (GND), U37.7 (GND), U38.7 (GND)
VCC: C3.1, C4.1, C5.1, C6.1, C7.1, C8.1, C9.1, C10.1, C11.1, C12.1, C13.1, C14.1, C15.1, C16.1, C17.1, C18.1, C19.1, C20.1, C21.1, C22.1, C23.1, J3.25 (+5V), R2.1, R3.1, RV1.2, RV1.3, RV2.2, RV2.3, U1.16 (VCC), U2.16 (VCC), U3.16 (VCC), U4.16 (VCC), U5.16, U6.14 (VCC), U7.14 (VCC), U8.14 (VCC), U9.14 (VCC), U10.14 (VCC), U11.14 (VCC), U12.14 (VCC), U13.14 (VCC), U14.14 (VCC), U15.14 (VCC), U16.14 (VCC), U17.14 (VCC), U18.14 (VCC), U19.14 (VCC), U20.14 (VCC), U21.14 (VCC), U22.14 (VCC), U23.14 (VCC), U24.14 (VCC), U25.14 (VCC), U26.14 (VCC), U27.14 (VCC), U28.14 (VCC), U29.14 (VCC), U30.14 (VCC), U31.14 (VCC), U32.16 (VCC), U33.14 (VCC), U34.14 (VCC), U35.14 (VCC), U36.14 (VCC), U37.14 (VCC), U38.14 (VCC)

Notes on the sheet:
CHIP POWER
UNUSED GATES
$C050/1
TIMING GENERATOR
FIXED AT 2K
SOFT SWITCHES
Latched data bus from Apple II video
OUTPUT CONNECTOR
BUS CONNECTOR AND CLOCK GENERATION
white=0
AMDEK DVM CARD
$C056/7
$C058/9
red#
$C05C/D
VIDEO MUX
1100 0000 0101 xxxx $C05x
HIRES SHIFT REG
80 column
COLOR DECODER
SYNC MUX
grn#
Only blue
1110x
VIDEO DATA LATCH
LSB
Reversed by Tube Time
MSB
SHIFT
$C052/3
Apple II B&W text
BYPASS CAPS
yel#
$C05E/F
$C054/5
MODE=1, parallel load on CP2 fall MODE=0, shift in on CP1 fall
Only green
$C05A/B
Only red
Pins 1-8: To 74LS161 interposer board Pins 9-16: To 74LS257 interposer board

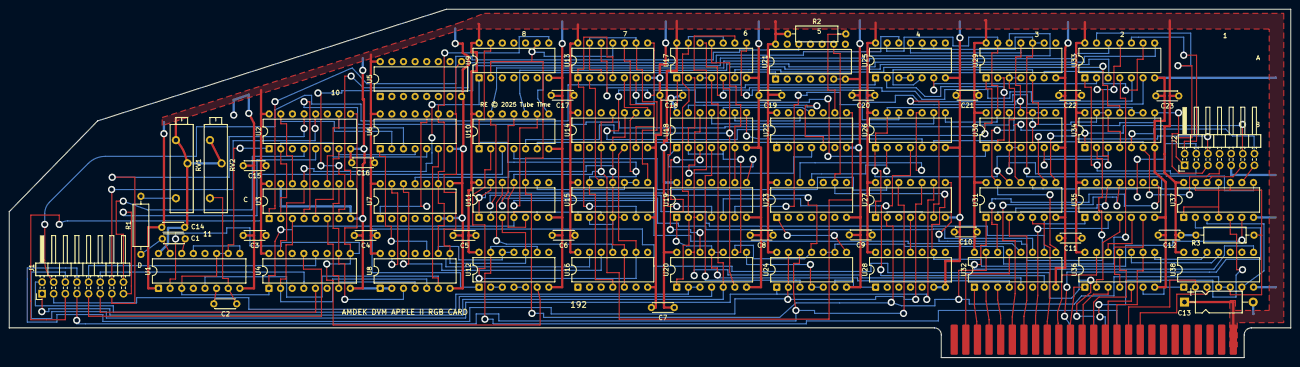
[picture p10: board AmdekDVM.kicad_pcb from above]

Board: 2 copper layers, 279.9 x 76.1 mm, 69 parts (0 on the bottom side), 153 nets.

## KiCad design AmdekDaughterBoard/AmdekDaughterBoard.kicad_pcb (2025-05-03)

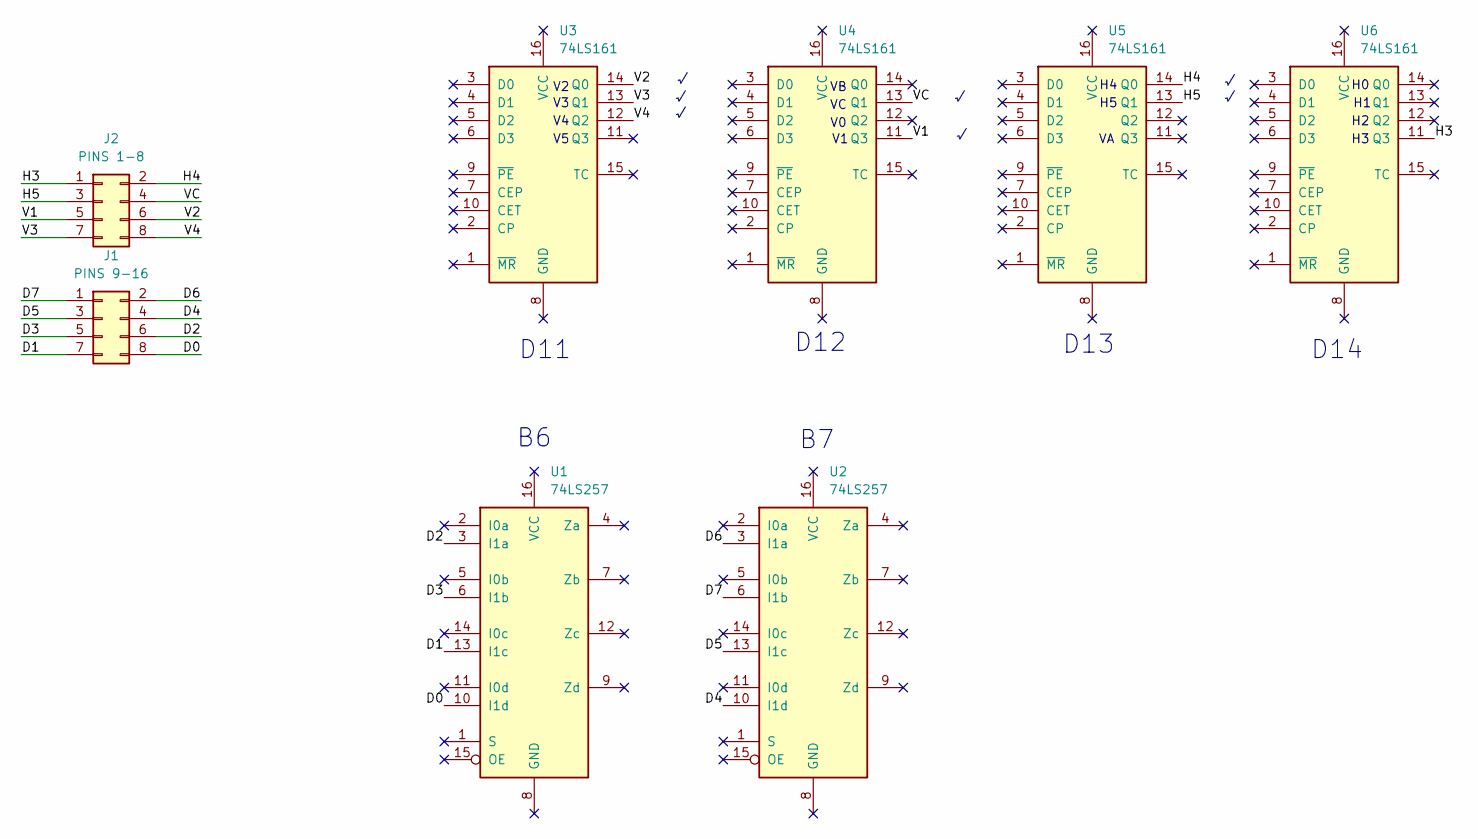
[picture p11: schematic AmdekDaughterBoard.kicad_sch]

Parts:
J1: PINS 9-16; PinHeader_2x04_P2.54mm_Vertical
J2: PINS 1-8; PinHeader_2x04_P2.54mm_Vertical
U1, U2: 74LS257; DIP-16_W7.62mm_Socket
U3, U4, U5, U6: 74LS161; DIP-16_W7.62mm_Socket

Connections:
/D0: J1.8, U1.10 (I1d)
/D1: J1.7, U1.13 (I1c)
/D2: J1.6, U1.3 (I1a)
/D3: J1.5, U1.6 (I1b)
/D4: J1.4, U2.10 (I1d)
/D5: J1.3, U2.13 (I1c)
/D6: J1.2, U2.3 (I1a)
/D7: J1.1, U2.6 (I1b)
/H3: J2.1, U6.11 (Q3)
/H4: J2.2, U5.14 (Q0)
/H5: J2.3, U5.13 (Q1)
/V1: J2.5, U4.11 (Q3)
/V2: J2.6, U3.14 (Q0)
/V3: J2.7, U3.13 (Q1)
/V4: J2.8, U3.12 (Q2)
/VC: J2.4, U4.13 (Q1)

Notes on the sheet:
D13
D14
D11
D12

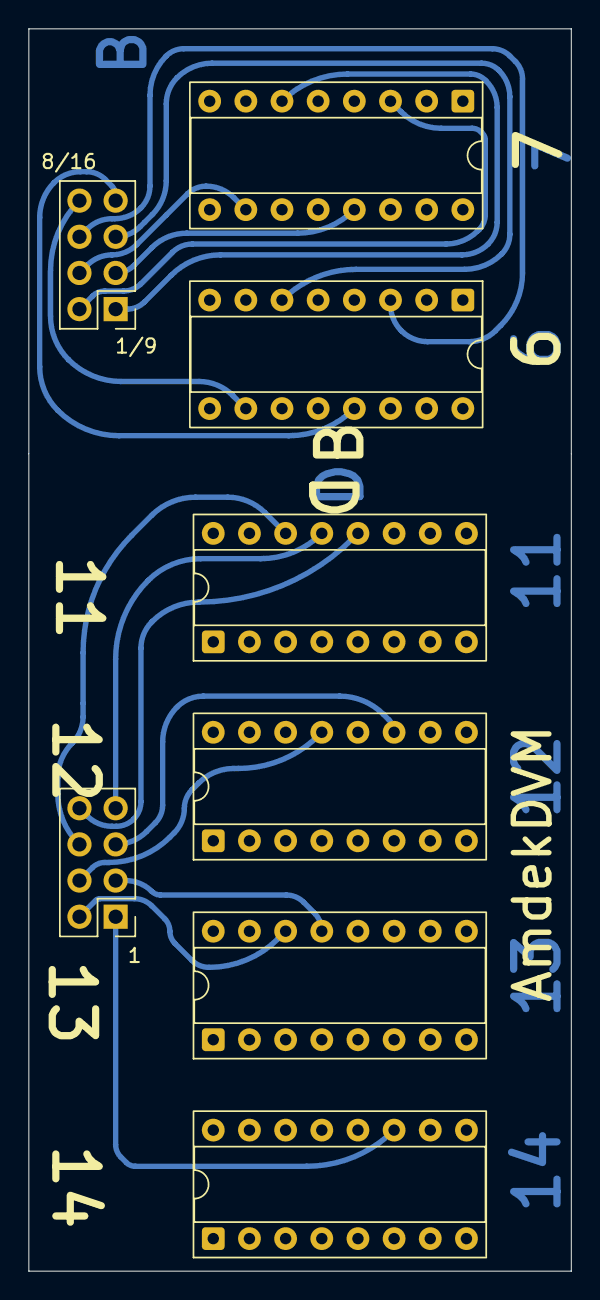
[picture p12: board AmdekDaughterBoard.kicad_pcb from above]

Board: 2 copper layers, 38.1 x 87.2 mm, 8 parts (0 on the bottom side), 16 nets.

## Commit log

2025-04-20 Add daughterboards
    [AmdekDVM.kicad_sch, AmdekDaughterBoard.kicad_pcb, AmdekDaughterBoard.kicad_sch]
2025-05-03 Add cable details, fab packages, instructions
    [AmdekDVM.csv, AmdekDVM.kicad_pcb, AmdekDVM.kicad_sch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]
2025-05-04 Correct video pinout
    [AmdekDVM.kicad_pcb, AmdekDVM.kicad_sch]

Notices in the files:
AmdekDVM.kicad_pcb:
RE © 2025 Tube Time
